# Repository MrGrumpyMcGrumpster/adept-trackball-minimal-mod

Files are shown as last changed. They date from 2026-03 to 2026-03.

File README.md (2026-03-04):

You have reached my fork of the [Main Ploopy Adept Trackball repository](https://github.com/ploopyco/adept-trackball), where you will find my Minimal Case Mod.  As these are just hardware modification to the existing Adept internals, all files will be located in the [Hardware/mechanicals-minimal-mod](https://github.com/MrGrumpyMcGrumpster/adept-trackball-minimal-mod/tree/master/hardware/mechanicals-minimal-mod) folder.

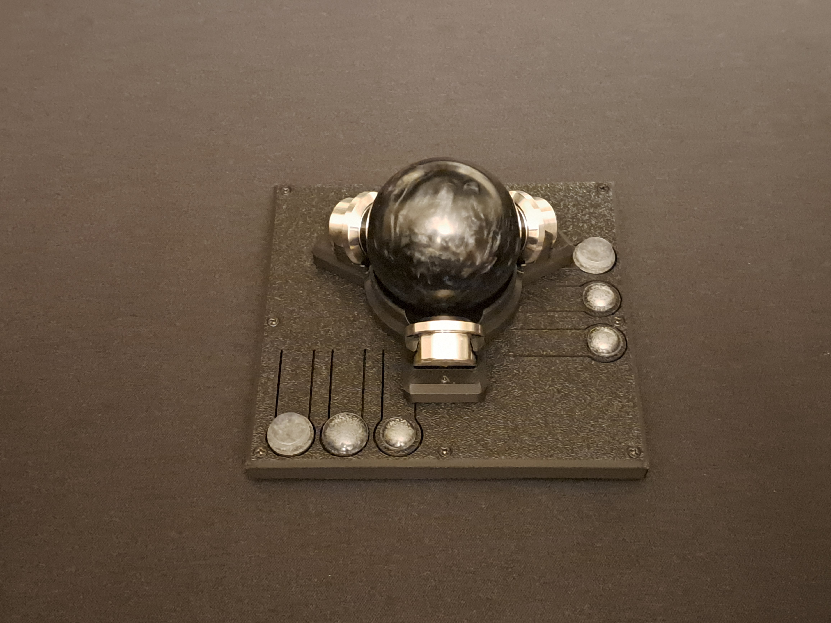
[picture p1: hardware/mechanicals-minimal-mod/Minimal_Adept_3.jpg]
Assembled


Best of luck!

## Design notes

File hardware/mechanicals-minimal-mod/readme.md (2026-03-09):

# The Ploopy Adept Trackball Minimal Mod

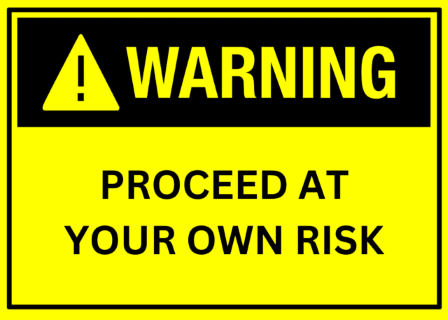
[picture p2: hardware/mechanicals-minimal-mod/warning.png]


This is the home of the "Minimal" case and board modification for the Ploopy Adept trackball.  I couldn't get
a comfortable hand position, so I created a new case and repositioned the buttons so I can reach them all
without having to move my hand.

While I was at it, I decided to try some different bearings.  Of the BTUs I've tried, the SP12 BTUs found on
AliExpress worked the best (for a while).  They're fairly smooth, and the noise wasn't excessive for my environment
(though still probably way too loud for most).  After additional testing however, I've found the SP12 units degrade
without maintenance. Most likely due to direct transfer of grit and grime to the enclosed support bearings.  I'm
a sweaty guy, and I'm afraid any BTU will be problematic if they aren't user servicable.  

  Update: A soak in 99% IPA did the trick.  BTUs are back in business!  Just have to keep 2 sets on hand, one in use
  and one being cleaned.

Please be advised that you will have to remove the 6 switches from the Adept board.  Soldering is required!
You should really have some extra Omron D2LS-21 switches as using the existing ones after desoldering them
can be hit or miss.  You'll also need to cut the two little locating nubs off the bottom of the switch.  They
should simply push right into the bottom plate.  

The images are all you need to figure it out really.  It really is just moving the board over to a newly printed
case and rewiring the switches.

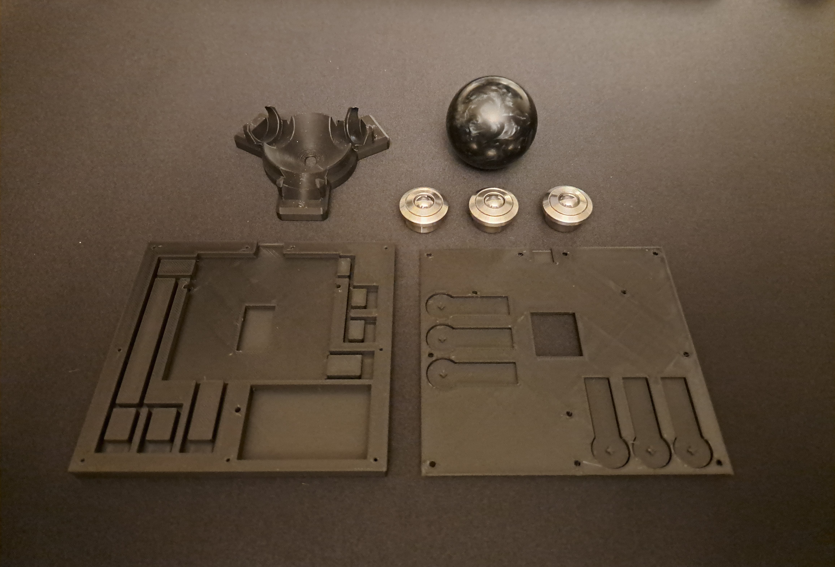
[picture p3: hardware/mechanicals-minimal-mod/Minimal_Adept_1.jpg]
The Minimal Adept Mod1

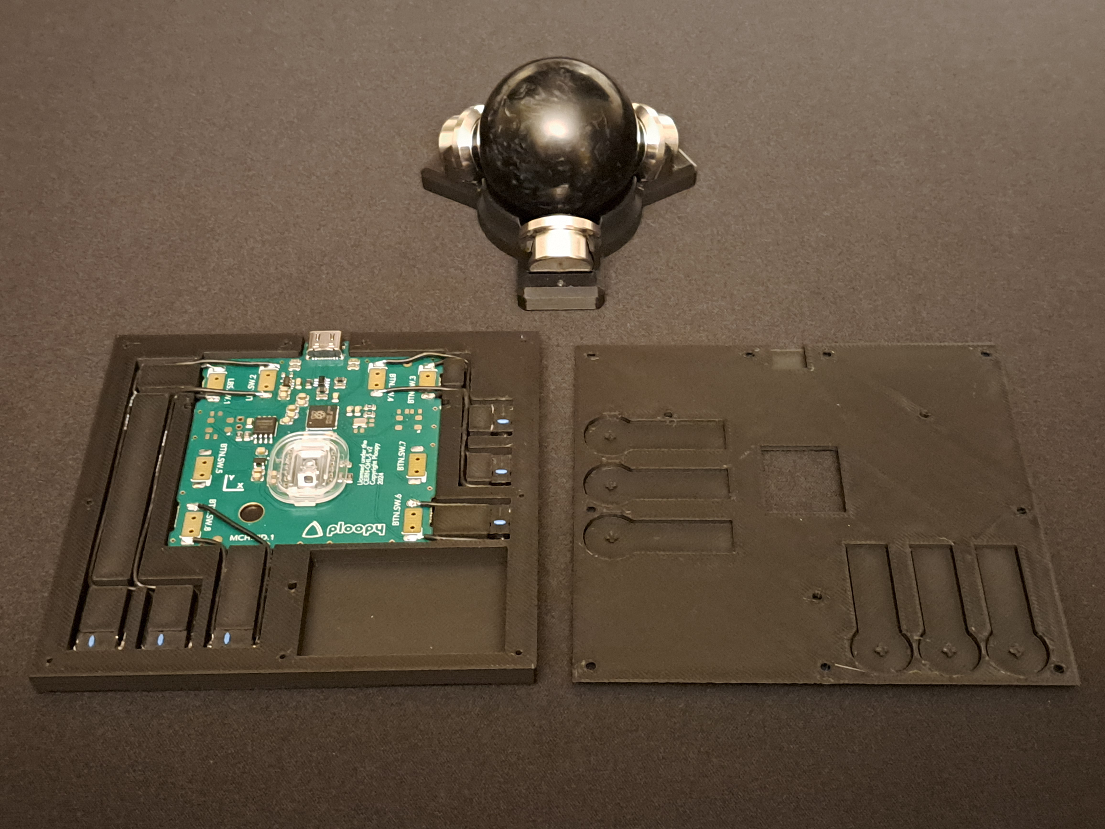
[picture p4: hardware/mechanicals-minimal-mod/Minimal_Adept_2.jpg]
The Minimal Adept Mod1

The Minimal Adept Mod1

Materials Needed:

  1) Ploopy Adept internals.  Please see the main [Ploopy Adept repository](https://github.com/ploopyco/adept-trackball).
  2) Extra Omron D2LS-21 switches highly recommended!
  3) 30 AWG stranded connection wire
  4) Soldering equipment, solder, etc...
  5) [SP12 BTUs](https://www.aliexpress.com/item/1005008220158916.html?spm=a2g0o.order_list.order_list_main.23.18df1802t6H6VG) : I believe most of the generic SP12 BTUs on Aliexpress are the same, but be aware that there are higher priced stainless steel versions.
  6) To hold the roller bearings, I use [M5x20mm grub screws](https://www.amazon.ca/dp/B0DM23GZT3) and [5x8x0.5mm washers](https://www.amazon.ca/dp/B0C53ZS4Q5) to keep the rolling surface from rubbing against the sides of the mount.
  7) Black countersunk screws (8 M2x8mm and 3 M2x16mm).  A [set like this](https://www.amazon.ca/dp/B07NZ3VSFX) is quite useful...
  8) [Rubber Antislip Dots](https://www.amazon.ca/dp/B0BZBXJ5Y8?th=1) for button tops and a non-slip base.  Different shapes for different primary buttons help with feel.
  9) A 3D Printer.
  10) A high quality 44mm ultra smooth trackball is ideal for roller bearings.  I currently use a [44mm unit](https://www.amazon.ca/dp/B0BQV1X86B) purchased from Amazon.

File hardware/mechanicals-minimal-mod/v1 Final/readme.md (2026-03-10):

# Please Note

1) Careful tightening down the srews, especially around the buttons.  There is very little material there.
2) Make sure you print the Main Case Top Plate with the top against the bed.  The buttons need the bed as support.

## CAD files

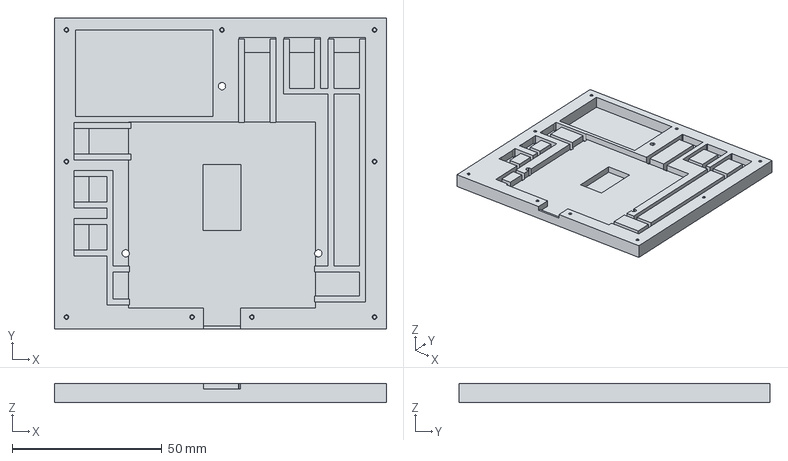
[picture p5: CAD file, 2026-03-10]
hardware/mechanicals-minimal-mod/v1 Final/Main Case - Bottom Plate.step
111.0 x 104.0 x 6.51 mm

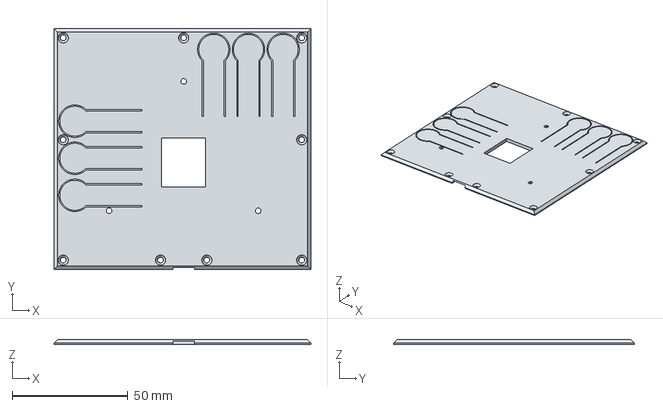
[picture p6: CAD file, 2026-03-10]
hardware/mechanicals-minimal-mod/v1 Final/Main Case - Top Plate.step
111.0 x 104.0 x 2.00 mm

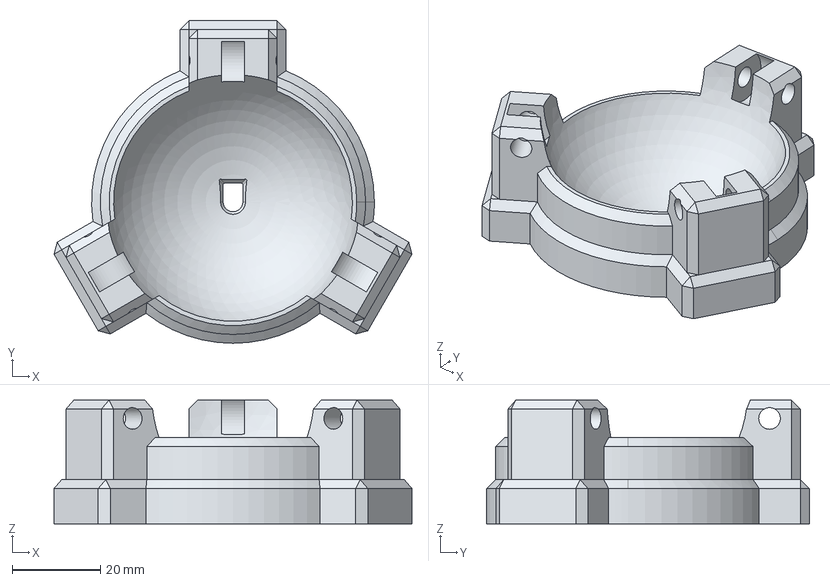
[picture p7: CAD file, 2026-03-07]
hardware/mechanicals-minimal-mod/v1 Final/Mounting Plate (3x MR105 at 80 Degrees) for 55mm Trackballs.step
81.0 x 73.0 x 28.0 mm

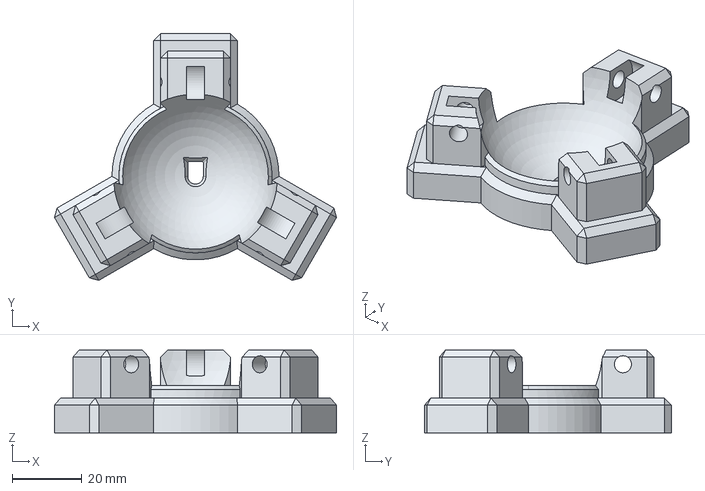
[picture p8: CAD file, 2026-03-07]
hardware/mechanicals-minimal-mod/v1 Final/Mounting Plate (3x MR105 at 80 degrees) for 45mm Trackballs.step
81.0 x 70.9 x 23.8 mm

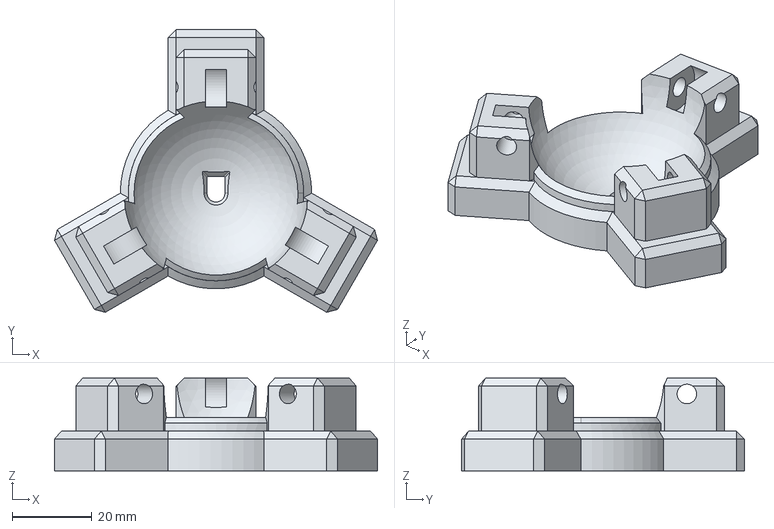
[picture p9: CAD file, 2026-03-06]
hardware/mechanicals-minimal-mod/v1 Final/Mounting Plate (3x MR105 at 80 Degrees) for 44mm Trackballs.step
81.0 x 70.9 x 23.3 mm

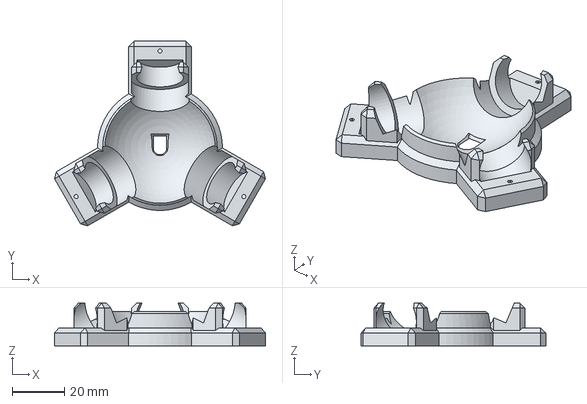
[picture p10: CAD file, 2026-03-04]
hardware/mechanicals-minimal-mod/v1 Final/Mounting Plate (3x SP12 BTUs) for 44mm or 45mm Trackballs.step
81.0 x 70.9 x 16.5 mm

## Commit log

2026-03-04 Added initial set of files.
    [44mm Trackball Plate (SP12 BTUs).step, Main Case - Bottom Plate.step, Main Case - Top Plate.step]
2026-03-04 Update readme with mod instructions and materials
2026-03-06 Finalized v1 step files
    [44mm Trackball Plate (3x MR105 at 80 Degrees).step, 44mm Trackball Plate (3x SP12 BTUs).step, 55mm Plate (3x MR105 at 80 Degrees).step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]
2026-03-07 Revise readme with updated bearing information
    Updated the readme to reflect changes in bearing performance and recommendations, including the need for maintenance and serviceability. Added details about the ideal trackball and bearing specificat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
2026-03-07 Update readme with installation instructions and edits
    Clarified instructions for switch installation and updated text for clarity.
2026-03-07 Clarify trackball recommendation in readme
    Reworded item 10 for clarity and removed comparison to the 45mm stock ball.
2026-03-07 Add plate for stock 45mm trackball
    [45mm Plate (3x MR105 at 80 degrees) Final.step]
2026-03-07 Revised Names for mounting plates.
    [Mounting Plate (3x MR105 at 80 Degrees) for 44mm Trackballs.step, Mounting Plate (3x MR105 at 80 Degrees) for 55mm Trackballs.step, Mounting Plate (3x MR105 at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]
2026-03-09 Revise bearing recommendations and maintenance advice
    Updated recommendations for bearings and maintenance tips.
2026-03-10 Add caution note for screw tightening in readme
    Added a note about careful tightening of screws around buttons.
2026-03-10 Update readme with printing instructions
    Added a note about printing the Main Case Top Plate with support.
